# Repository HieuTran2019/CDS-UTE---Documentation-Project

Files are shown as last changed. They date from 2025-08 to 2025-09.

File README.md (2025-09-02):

# CDS-UTE Tài liệu

Cuộc thi Xe tự hành ứng dụng Xử lý ảnh và Trí tuệ nhân tạo - Tài liệu

Đây là kho lưu trữ tài liệu cho cuộc thi nội bộ về xe tự hành, áp dụng các kỹ thuật xử lý ảnh và trí tuệ nhân tạo.  
Trang Web tài liệu online: [CDS-UTE Documentation](https://cds-ute-documentation-project.readthedocs.io/en/latest/)

📌 **Mục tiêu:** Thiết kế và triển khai hệ thống xe tự hành có khả năng nhận diện làn đường, vật cản và thực hiện điều hướng tự động trong môi trường giả lập hoặc thực tế.

## Nội dung tài liệu

- Giới thiệu dự án
- Kiến trúc hệ thống
- Xử lý ảnh (Image Processing)
- Mô hình AI và điều khiển
- Môi trường mô phỏng và kiểm thử
- Tài liệu tham khảo

> Dự án lấy cảm hứng từ Bosch Future Mobility Challenge (BFMC), nhưng được tổ chức với quy mô nhỏ hơn, mang tính học thuật và thực hành.

---

📁 Đây chỉ là tài liệu nội bộ. Nếu bạn muốn đóng góp hoặc tham khảo thêm, hãy liên hệ team phát triển.

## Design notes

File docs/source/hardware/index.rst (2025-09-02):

Thông số chung và các thành phần
================================

.. toctree::
   :maxdepth: 1
   :caption: Nội dung:

   car/specs
   3d-models/in3D
   electronics/electronics

Tổng quan
-------------------

Đây là mô tả tổng quan của chiếc xe, với tất cả các thành phần của nó:

Mặt phía trên với các thành phần (minh họa ở hình 1):

- Orange Pi 5 Plus: bộ xử lý trung tâm, thực hiện các tác vụ AI, xử lý ảnh, nhận diện làn đường, biển báo và gửi tín hiệu điều khiển đến STM32.
- Board STM32F411RE: bộ điều khiển chính để điều khiển động cơ xe và servo.
- Camera Logitech: cung cấp hình ảnh cho Orange Pi.
- Công tắc nguồn: công tắc tổng, cấp nguồn từ pin LiPo 3S đến UBEC để cấp điện cho Orange Pi.
- Hai nút nhấn: nút xanh để khởi động STM32, nút đỏ để tắt chương trình chạy trên STM32.

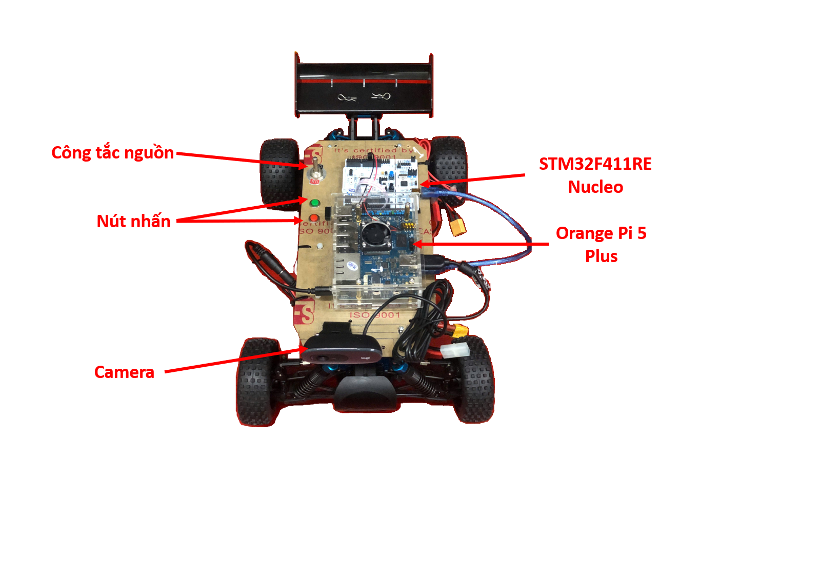
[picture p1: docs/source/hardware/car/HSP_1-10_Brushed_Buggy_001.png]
Xe HSP 1/10 Brushed Buggy


   **Hình 1.** Mặt trên của chiếc xe

------

Mặt dưới là các thành phần gồm(minh họa ở hình 2):

- Pin LiPo 3S: cung cấp điện cho Orange Pi.
- Pin Ni-MH 6 cell (7.2V) dung lượng 2000mAh: cung cấp điện cho motor và servo.
- Mạch UBEC 5V 8A: giúp ổn định nguồn 5V cho Orange Pi hoạt động.
- Mạch chia điện: do nhóm thiết kế, giúp đi dây gọn gàng, dễ thay thế, tích hợp cầu chì 3A bảo vệ servo.
- Servo: điều khiển cơ cấu lái.
- ESC: điều khiển động cơ.
- Động cơ: cung cấp mô-men xoắn, giúp xe chạy khỏe trên nhiều loại địa hình.

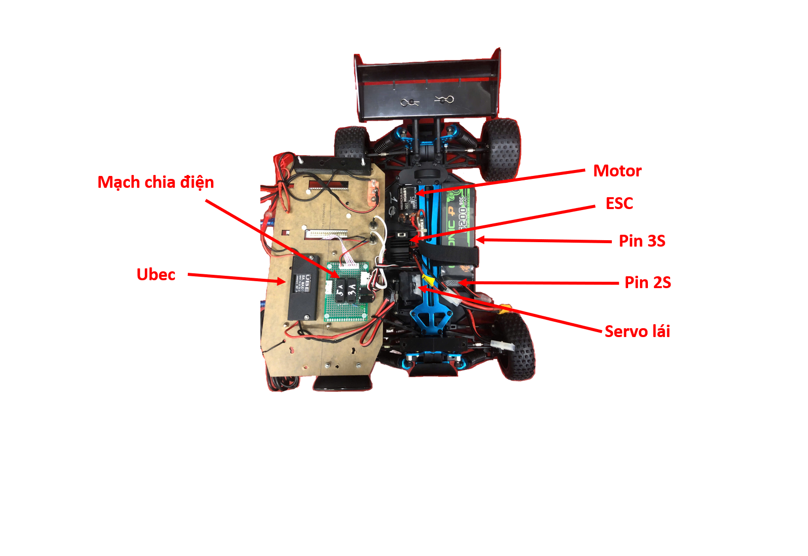
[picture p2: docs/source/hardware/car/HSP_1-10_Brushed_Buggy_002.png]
Xe HSP 1/10 Brushed Buggy


   **Hình 2.** Mặt dưới của chiếc xe

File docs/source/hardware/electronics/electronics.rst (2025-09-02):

Sơ đồ kết nối
----------------

Trong **Hình 1**, bạn có thể thấy sơ đồ kết nối của tất cả các thành phần phần cứng của xe. 
Các chân GPIO được đánh dấu trực tiếp trên từng thành phần.

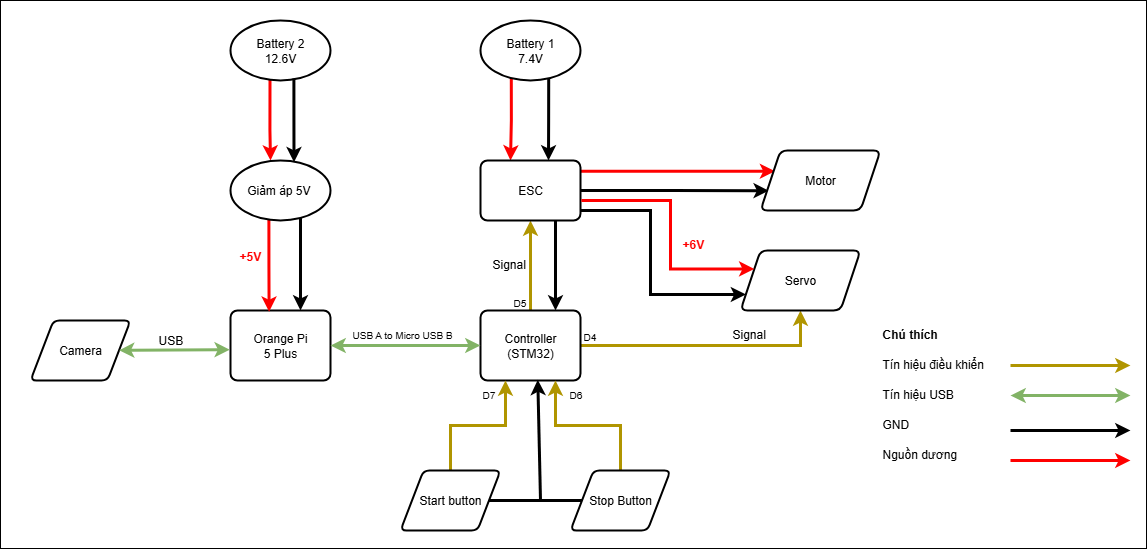
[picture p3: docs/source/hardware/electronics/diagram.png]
Sơ đồ kết nối phần cứng


   **Hình 1.** Sơ đồ kết nối tổng thể

Hệ thống sẽ sử dụng **hai cục pin**:

- **Pin LiPo 3S**: cung cấp điện cho Orange Pi, đi qua UBEC 5V (mạch giảm áp) để hạ áp xuống mức 5V.  
  UBEC giúp ổn định điện áp 5V và cung cấp dòng cao, đảm bảo Orange Pi hoạt động tốt.  

- **Pin Ni-MH 6 cell**: cung cấp điện cho ESC để điều khiển động cơ.  
  Đồng thời nguồn từ ESC cũng cấp cho servo, nhưng được đưa qua một cầu chì 3A để tránh quá tải, bảo vệ servo.  

**STM32** được cấp nguồn thông qua cổng USB mini từ Orange Pi.  
Cần chú ý jumper trên board STM32 phải chọn **USB** thay vì **E5V** (vị trí khoanh đỏ số 1 trong Hình 2).  
Ngoài ra, dù sử dụng nhiều nguồn khác nhau, tất cả cần **đồng bộ chung GND** để tín hiệu điều khiển chính xác (xem Hình 2 và Hình 3).  

STM32 được kết nối đến **mạch chia điện** thông qua dây bus (ô đỏ số 3 trong Hình 2).  
Cần chú ý hướng cắm, chân bắt đầu từ D7 đến D2.  

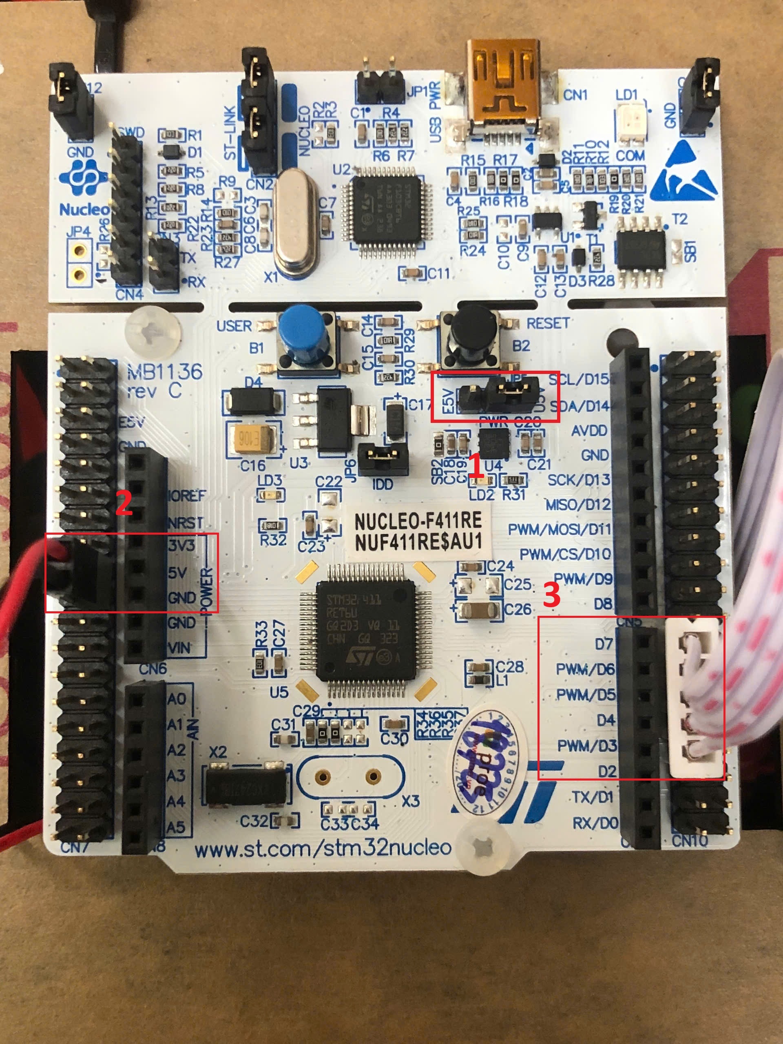
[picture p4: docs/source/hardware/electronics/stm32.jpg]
STM32 kết nối nguồn và mạch chia điện


   **Hình 2.** STM32 và các kết nối quan trọng

Đây là **mạch chia điện**, các đầu connector được thiết kế giống với sơ đồ tổng thể ở Hình 1.  
Các đầu nối loại XH2.54mm giúp việc thay thế và sửa chữa thuận tiện hơn.  
Trên board còn có **LED màu xanh lá** để báo hiệu có điện từ ESC.

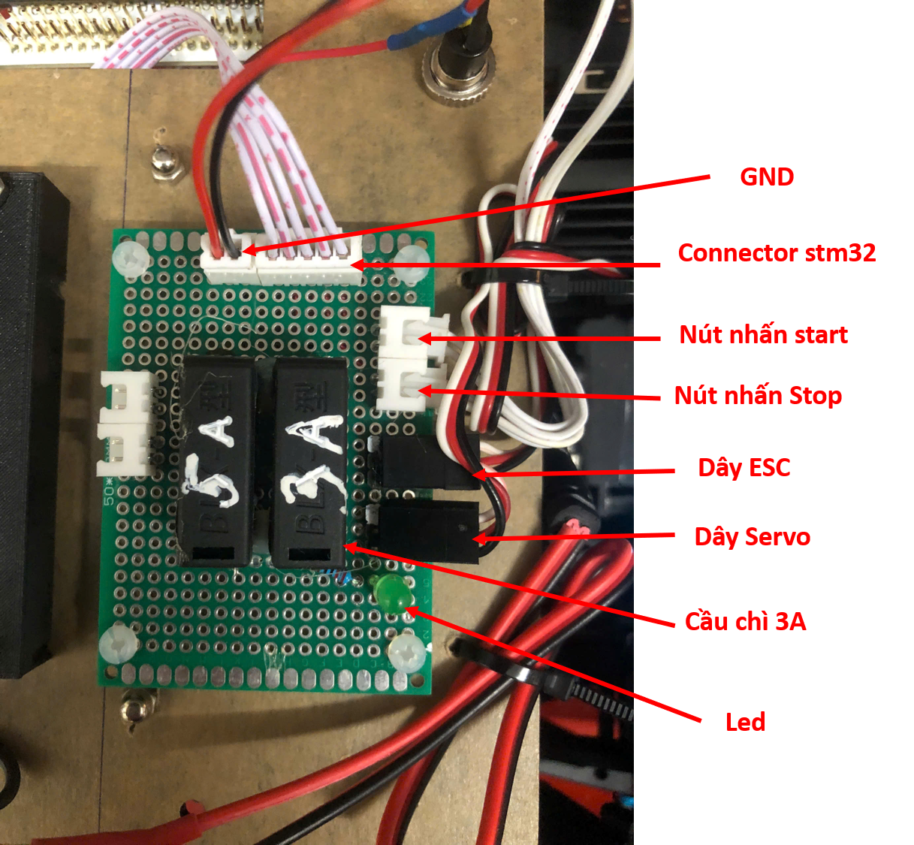
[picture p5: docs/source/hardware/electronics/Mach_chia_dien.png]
Mạch chia điện


   **Hình 3.** Mạch chia điện

Xe được trang bị **hai nút nhấn** (màu xanh và màu đỏ), đều được lập trình bằng ngắt ngoài:  

- **Nút đỏ**: dừng chương trình điều khiển. Khi nhấn, tốc độ (`speed`) và góc lái (`angle`) sẽ trở về 0, đồng thời LED P13 tắt (Hình 4).  

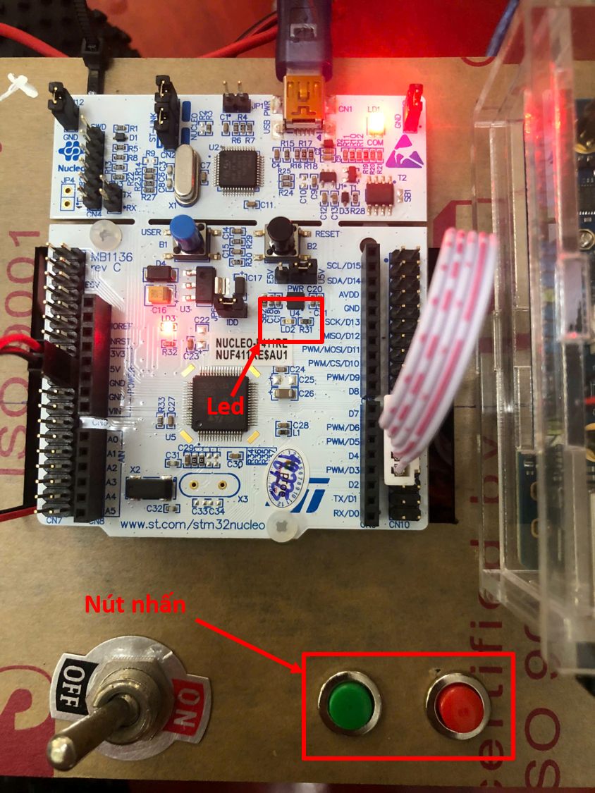
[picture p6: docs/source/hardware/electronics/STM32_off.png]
Nút đỏ dừng chương trình, LED P13 tắt


   **Hình 4.** Trạng thái khi dừng chương trình (nút đỏ – LED P13 tắt)

- **Nút xanh**: khởi động chương trình điều khiển trong STM32. Khi nhấn, LED P13 trên board STM32 sáng và chương trình bắt đầu chạy (Hình 5).  

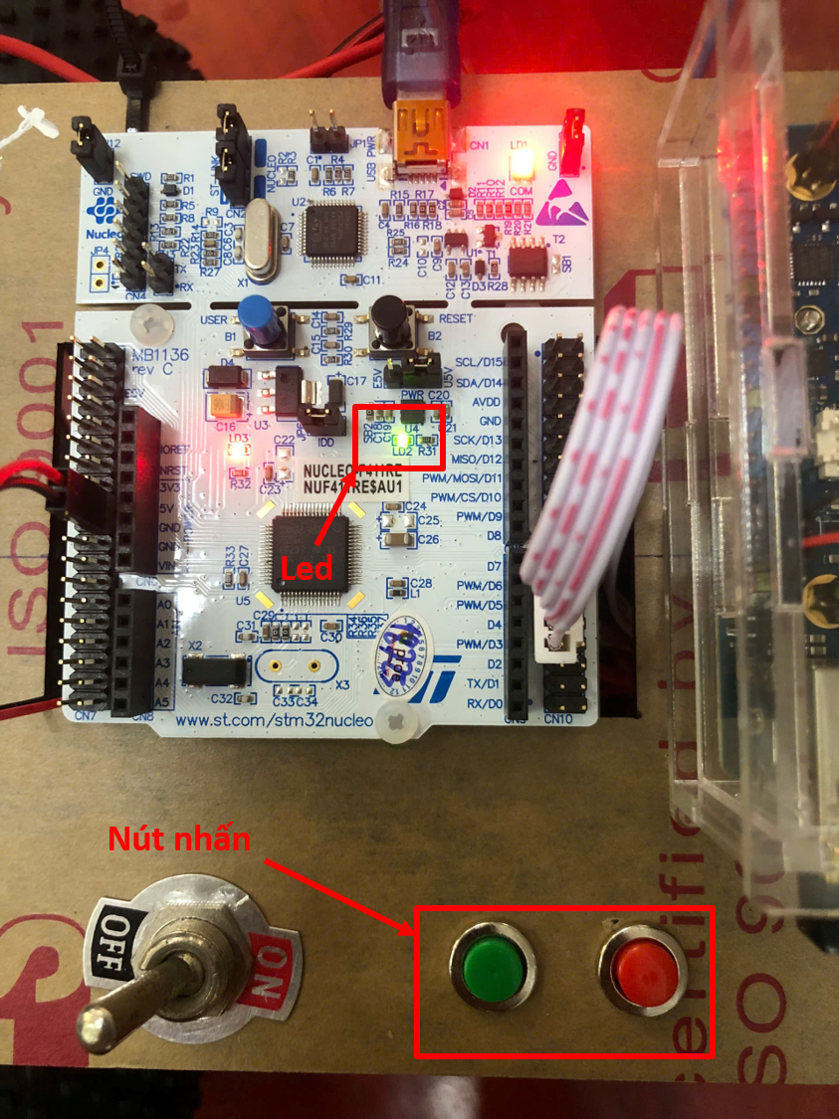
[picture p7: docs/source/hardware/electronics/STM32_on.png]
Nút xanh khởi động chương trình, LED P13 sáng


   **Hình 5.** Trạng thái khi chạy chương trình (nút xanh – LED P13 sáng)

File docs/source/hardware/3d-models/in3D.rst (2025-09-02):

Các thành phần in 3D
--------------------

Và đây là các thành phần in 3D cho chính chiếc xe. Chúng hỗ trợ liên kết các bộ phận lên khung xe. Các khối 3D trong đây là dạng tham khảo. 
Các bạn hoàn toàn có thể tự thiết kế cho mình các mẫu riêng cho bản thân
Cũng có sẵn ở định dạng có thể chỉnh sửa, như tiện ích mở rộng SLDPRT tại liên kết này: 
`solid parts <https://github.com/HieuTran2019/CDS-UTE---Documentation-Project/tree/main/docs/source/hardware/3d-models/CarSpareParts/sldprt>`_

- `Giá đỡ Camera <https://github.com/HieuTran2019/CDS-UTE---Documentation-Project/blob/main/docs/source/hardware/3d-models/CarSpareParts/C270_2020_mount.stl>`_  

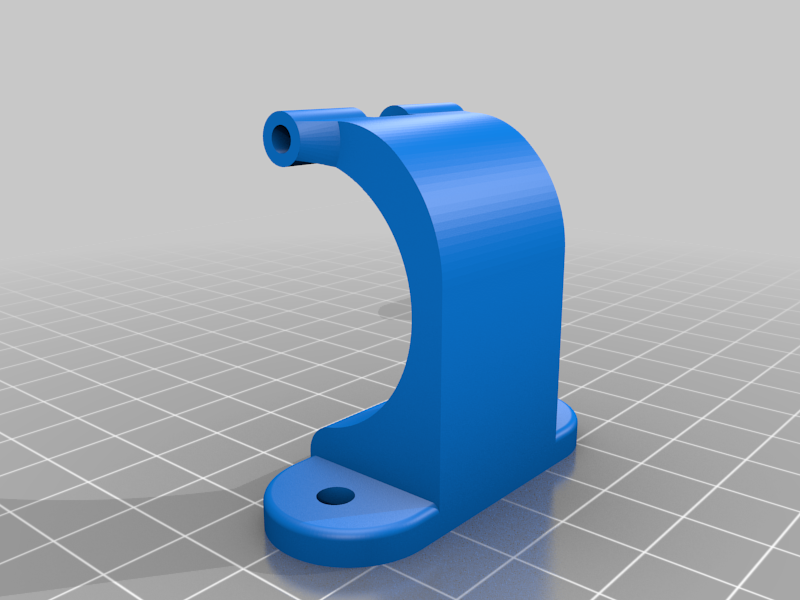
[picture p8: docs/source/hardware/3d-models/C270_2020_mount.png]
Giá đỡ Camera Logitech C270
  

- `Tấm đỡ phía sau <https://github.com/HieuTran2019/CDS-UTE---Documentation-Project/blob/main/docs/source/hardware/3d-models/CarSpareParts/besauv2.STL>`_  

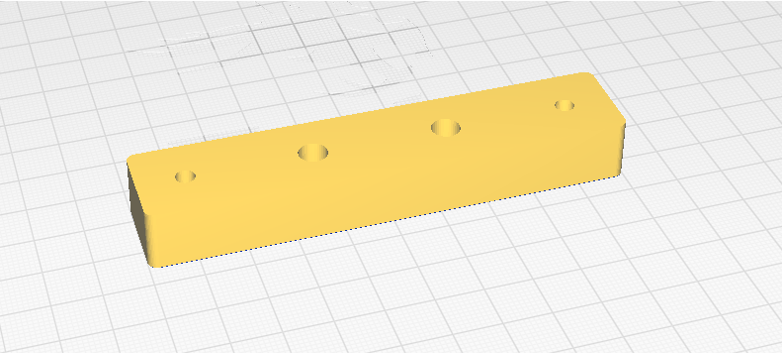
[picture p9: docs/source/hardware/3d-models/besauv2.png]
Tấm đỡ phía sau
  

- `Bệ Ubec <https://github.com/HieuTran2019/CDS-UTE---Documentation-Project/blob/main/docs/source/hardware/3d-models/CarSpareParts/be_ubec.STL>`_  

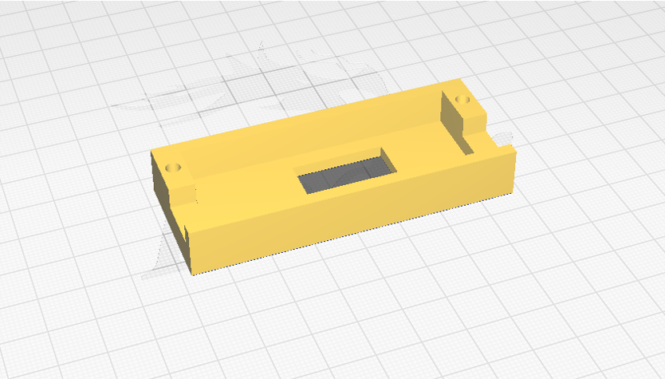
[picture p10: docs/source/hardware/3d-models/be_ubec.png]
Bệ đỡ Ubec
  

- `Bệ pin <https://github.com/HieuTran2019/CDS-UTE---Documentation-Project/blob/main/docs/source/hardware/3d-models/CarSpareParts/depin.STL>`_  

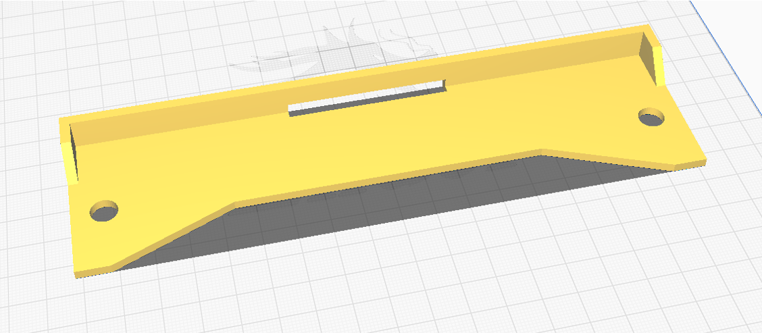
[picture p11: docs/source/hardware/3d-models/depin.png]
Bệ đỡ pin
  

- `Tấm mica <https://github.com/HieuTran2019/CDS-UTE---Documentation-Project/blob/main/docs/source/hardware/3d-models/CarSpareParts/matngang_V4.DXF>`_  

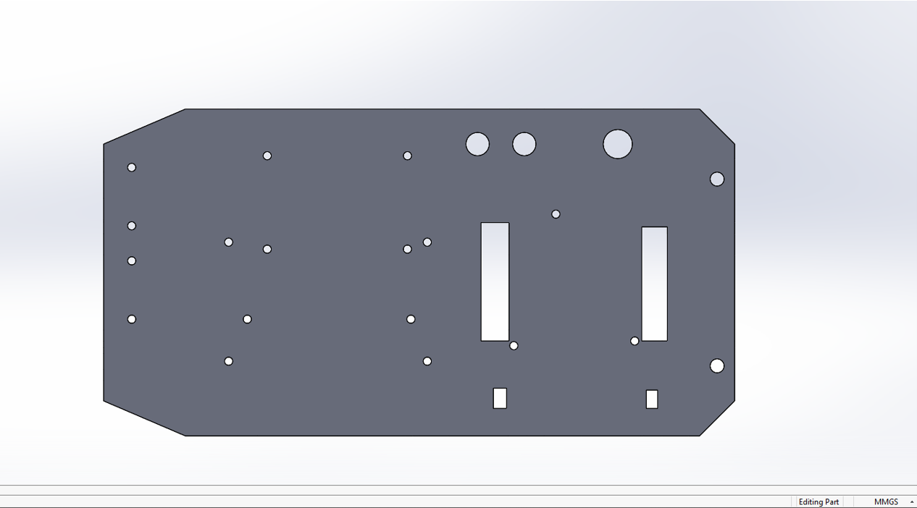
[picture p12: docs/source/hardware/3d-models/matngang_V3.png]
Tấm mica ngang
  

- `Bệ đỡ trước <https://github.com/HieuTran2019/CDS-UTE---Documentation-Project/blob/main/docs/source/hardware/3d-models/CarSpareParts/betruoc_lan2.STL>`_  

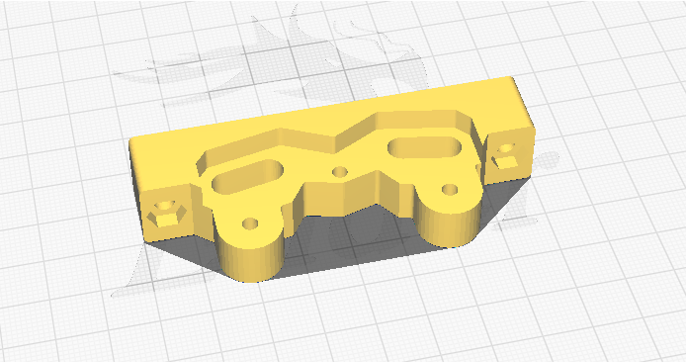
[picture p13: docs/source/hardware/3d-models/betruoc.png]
Bệ đỡ trước


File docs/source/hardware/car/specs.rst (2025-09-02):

Thành phần chi tiết
===================

Dưới đây là thông tin chi tiết các thành phần có trên xe bao gồm hình ảnh minh họa, đường link mua sản phẩm

- `Chassis <https://www.stormracer.com/sanpham/xe-dieu-khien/1-10-electric-xe-dien/hsp-1-10-electric-buggy-4wd-94107_01030089.product>`_ 

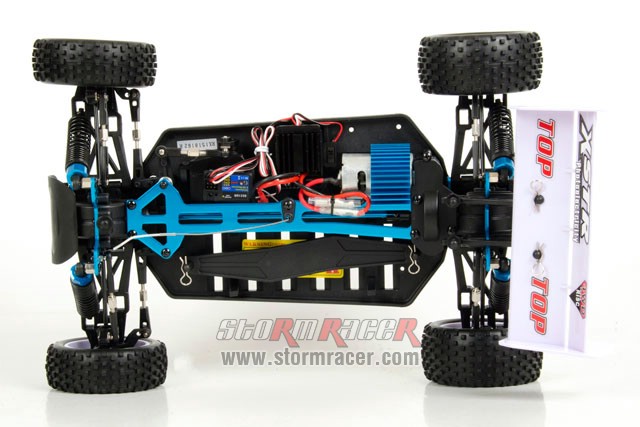
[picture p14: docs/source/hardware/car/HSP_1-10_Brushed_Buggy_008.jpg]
Chassis xe


- `Servo <https://www.stormracer.com/sanpham/xe-dieu-khien/1-10-electric-xe-dien/hsp-1-10-electric-buggy-4wd-94107_01030089.product>`_  

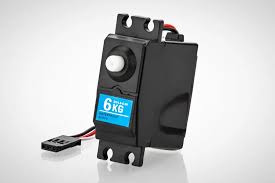
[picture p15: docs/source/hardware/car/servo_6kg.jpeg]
Servo 6kg


- `Motor 50T <https://www.stormracer.com/sanpham/dong-co-dien/motor-dien-for-rc-car/modified-motor-rs-540-50t-high-torque-brushed-motor_12050010.product>`_  
  
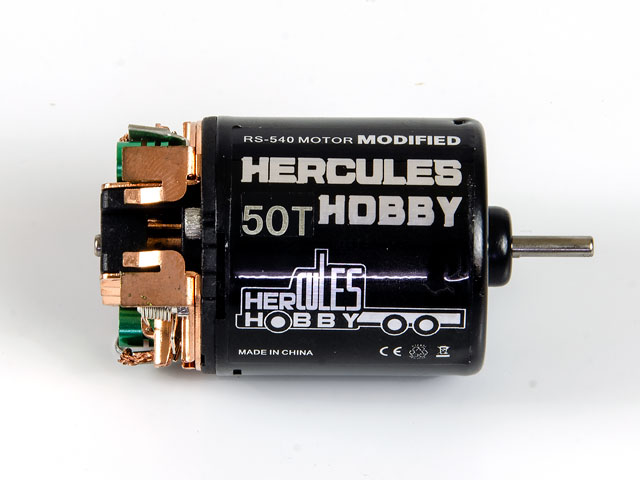
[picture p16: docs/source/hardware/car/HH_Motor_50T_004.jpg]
Động cơ RS-540 50T


- `Controller (STM32 Nucleo F411RE) <https://www.proe.vn/kit-stm32f411-nucleo-nucleo-f411re>`_  

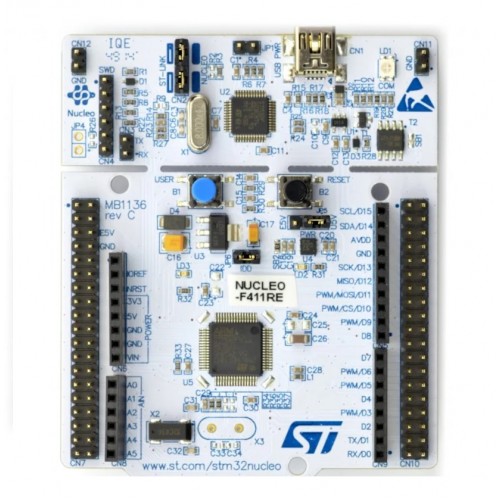
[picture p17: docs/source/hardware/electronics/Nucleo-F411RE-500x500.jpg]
STM32 Nucleo F411RE


- `Camera Logitech C270 <https://tinhocngoisao.com/products/webcam-logitech-c270-hd-720p>`_  

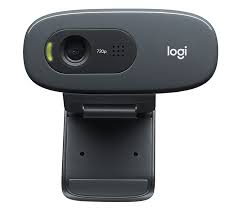
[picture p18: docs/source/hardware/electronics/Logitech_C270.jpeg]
Camera Logitech C270


- `Battery (Vant Lipo 3S 5200mAh 50C) <https://www.stormracer.com/sanpham/pin-may-sac/pin-lipo-lipo-battery/vant-battery-lipo-3s-111v-5200mah-50c-grade-a_11030088.product>`_  

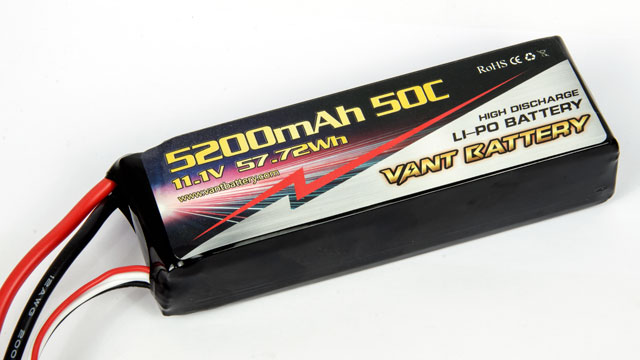
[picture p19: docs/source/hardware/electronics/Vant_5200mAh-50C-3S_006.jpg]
Pin Lipo 3S 5200mAh


.. - `IMU Sensor (BNO055) <https://www.proe.vn/adafruit-9-dof-absolute-orientation-imu-fusion-breakout-bno055>`_  

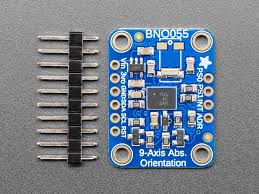
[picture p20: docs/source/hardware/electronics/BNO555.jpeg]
.. 
..     :alt: Cảm biến IMU BNO055
..     :width: 250px
..     :align: center

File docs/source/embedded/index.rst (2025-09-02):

Lập trình điều khiển
======================

Tổng quan
---------

Chương trình sẽ cung cấp cho bạn một giá trị đầu vào:

- **image**: hình ảnh trả về từ xe.  
- **Hàm điều khiển**: `control(speed, angle)` với các tham số:  

  + `angle` (góc điều khiển): giá trị trong khoảng **[-25, 25]**  
    *Âm* → góc trái, *Dương* → góc phải  

  + `speed` (tốc độ điều khiển): giá trị trong khoảng **[-25, 50]**  
    *Âm* → lùi, *Dương* → tiến  

Hướng dẫn chạy chương trình
---------------------------

Xem code tại repo:  

`CDS_UTE_2025 <https://github.com/HieuTran2019/CDS_UTE_2025>`_

Trước khi chạy, bạn cần chỉnh **port** mà STM32 kết nối với Orange Pi.  
Trên Orange Pi, thông thường port sẽ là **/dev/ttyACM0**  

port

Sau đó, để khởi chạy chương trình điều khiển, bạn dùng lệnh:

.. code-block:: bash

   python client.py

Khi chạy, tín hiệu **speed** và **angle** sẽ được gửi từ Orange Pi đến STM32 thông qua cổng **STLink** (dây cáp USB).  

**Lưu ý:** đảm bảo bạn đã nhấn nút **Start (màu xanh lá)** và LED on-board trên STM32 đã sáng.  

Hướng dẫn code STM32
---------------------

Trong dự án này, STM32 được lập trình bằng công cụ **Arduino IDE**.  
Bạn có thể xem hướng dẫn chi tiết tại:  

`utils/README.md <https://github.com/HieuTran2019/CDS_UTE_2025/blob/main/utils/README.md>`_

Phiên bản code **Control_CDS_ver3** là phiên bản hoàn thiện cuối cùng.  
Tuy nhiên, bạn hoàn toàn có thể hiệu chỉnh các tham số hoặc mở rộng thêm nếu muốn.  

Điều chỉnh tốc độ và góc lái
----------------------------

Dưới đây là hai phần hướng dẫn chi tiết để hiệu chỉnh:

.. toctree::
   :maxdepth: 2
   :caption: Nội dung:

   img/speed
   img/angle

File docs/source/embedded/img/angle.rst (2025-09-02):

Hiệu chỉnh góc lái
==================

Mỗi chiếc xe RC đều được lắp ráp tỉ mỉ, tuy nhiên có thể tồn tại sai số nhỏ trong hiệu chỉnh góc lái do cơ cấu cơ khí.  
Ví dụ: khi bạn đặt góc lái thẳng (90°), bánh xe thực tế có thể lệch vài độ sang trái hoặc phải. Đây không phải lỗi, mà là đặc điểm tự nhiên của quá trình lắp ráp thủ công.

Giải pháp
---------

Để khắc phục sai số này, tôi thiết lập các tham số khởi tạo nhằm giới hạn và hiệu chỉnh lại góc lái.

Tham khảo code Arduino tại đây:  
`Control_CDS_ver3.ino <https://github.com/HieuTran2019/CDS_UTE_2025/blob/main/utils/Control_CDS_ver3/Control_CDS_ver3.ino>`_

Ở đầu code, bạn sẽ thấy các tham số cố định (Hình 1):

Tham số cấu hình góc lái

   **Hình 1.** Các tham số cấu hình góc lái trong code

Nguyên lý tín hiệu Servo
------------------------

Servo lái được điều khiển dựa vào độ rộng xung PWM:

- **1000µs → 1500µs**: quay sang trái (0° → 90°)  
- **1500µs**: vị trí trung tâm (90°)  
- **1500µs → 2000µs**: quay sang phải (90° → 180°)  

Một số điểm quan trọng:

- Cơ cấu lái thực tế của xe **không sử dụng toàn bộ dải 0° → 180° của servo**.  
  Giới hạn an toàn thường nằm trong khoảng **50° → 130°**.  
- Vượt quá giới hạn này có thể khiến servo bị kẹt, quá tải và cháy; hoặc làm gãy các khớp cơ khí (Hình 2).  
- Nếu ở vị trí **90° không trùng với hướng thẳng của xe**, bạn có thể hiệu chỉnh lại bằng tham số `SERVO_CENTER`.

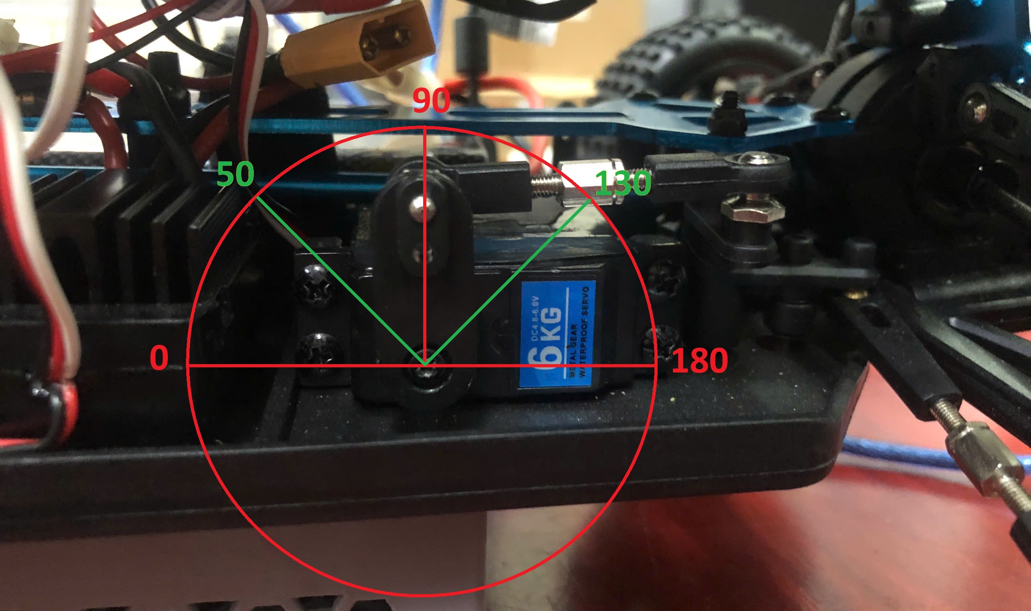
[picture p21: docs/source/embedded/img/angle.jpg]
Giới hạn góc lái


   **Hình 2.** Giới hạn góc lái an toàn

Tổng kết các tham số
--------------------

Bạn có thể tinh chỉnh lại các tham số góc lái để phù hợp với từng xe:

1. Chỉnh sửa trong file code Arduino  
   `Control_CDS_ver3.ino <https://github.com/HieuTran2019/CDS_UTE_2025/blob/main/utils/Control_CDS_ver3/Control_CDS_ver3.ino>`_:

- `SERVO_LEFT_MAX  = 50;`   → Góc trái tối đa  
- `SERVO_CENTER    = 90;`   → Vị trí trung tâm  
- `SERVO_RIGHT_MAX = 130;`  → Góc phải tối đa  

2. Chỉnh sửa trong file Python  
   `control.py <https://github.com/HieuTran2019/CDS_UTE_2025/blob/main/utils/control.py>`_:

- `speed = max(min(speed, 50), -25)`  
  → Giới hạn tốc độ do phần mềm. Xe không bao giờ vượt quá 50 (tiến) hoặc -25 (lùi).  

- `angle = max(min(angle, 25), -25)`  
  → Giới hạn góc lái trong khoảng [-25°, 25°] để tránh servo vượt quá giới hạn cơ khí.  

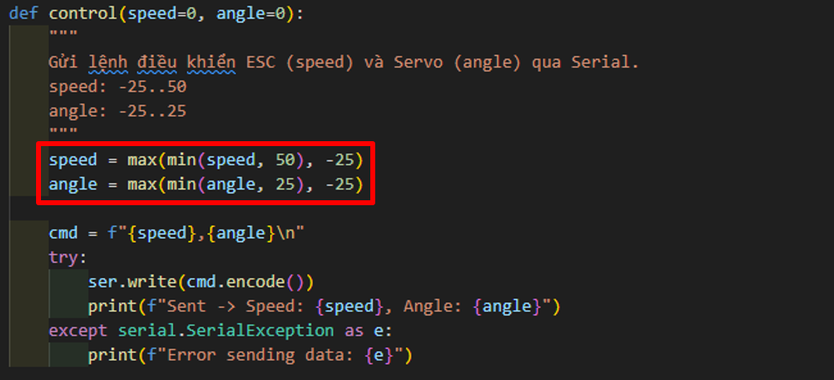
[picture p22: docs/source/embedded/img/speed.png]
Giới hạn tốc độ


   **Hình 3.** Điều chỉnh giới hạn tốc độ trong code

Ví dụ cấu hình:

.. code-block:: cpp

    // Giới hạn servo lái
    const int SERVO_LEFT_MAX  = 50;   // Góc trái tối đa
    const int SERVO_CENTER    = 90;   // Trung tâm
    const int SERVO_RIGHT_MAX = 130;  // Góc phải tối đa

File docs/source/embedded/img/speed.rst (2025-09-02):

Hiệu chỉnh tốc độ
=================

Như một phần trong cam kết mang đến trải nghiệm tốt nhất, mỗi người tham gia sẽ nhận được một chiếc xe RC đã được lắp ráp tỉ mỉ.  
Tuy nhiên, có thể tồn tại những sai số nhỏ trong hiệu chỉnh tốc độ do quá trình lắp ráp thủ công.  

Đây không phải là lỗi, mà là đặc điểm tự nhiên trong sản xuất và có thể hiệu chỉnh bằng phần mềm.

Giải pháp
---------

Để khắc phục sai số này, tôi đã thiết lập các tham số khởi tạo nhằm xử lý những sai số nhỏ này trong hiệu chỉnh góc lại.

Về điều khiển, tôi sử dụng **thư viện Servo** để điều khiển ESC (Electronic Speed Controller), vì ESC cũng nhận tín hiệu xung trong khoảng **1000µs → 2000µs**.

Tham khảo code Arduino tại đây:  
`Control_CDS_ver3.ino <https://github.com/HieuTran2019/CDS_UTE_2025/blob/main/utils/Control_CDS_ver3/Control_CDS_ver3.ino>`_

Ở đầu code, bạn sẽ thấy các tham số cố định (Hình 1):

Tham số cấu hình PWM

   **Hình 1.** Các tham số cấu hình PWM trong code

Nguyên lý tín hiệu ESC
----------------------

ESC điều khiển tiến/lùi dựa vào độ rộng xung PWM:

- **1000µs → 1500µs**: Lùi (-100% → 0%)  
- **1500µs**: Trung tính (0%, xe dừng)  
- **1500µs → 2000µs**: Tiến (0% → 100%)  

Một số điểm quan trọng:

- Nếu không cần tốc độ tối đa, hãy **giới hạn PWM_FORWARD_MAX**  
  Ví dụ: `PWM_FORWARD_MAX = 1700` → tốc độ tối đa chậm hơn so với 2000µs.

- Khi lùi:  

  1. Gửi tín hiệu nhỏ hơn 1300µs (ví dụ 1200µs) trong ~300ms để ESC xác nhận.  
  2. Trả lại **neutral = 1500µs**.  
  3. Sau đó mới gửi dải xung 1500 → 1000µs để xe lùi.  

- Khi phanh:  
  Nếu xe đang chạy tiến (`> 1500µs`), chỉ cần gửi tín hiệu `< 1200µs`, xe sẽ **phanh gấp**.  
  Cách này hiệu quả hơn so với chỉ trả về **1500µs** (xe sẽ trôi). (chưa tích hợp vào code Control_CDS_ver3)  

Hàm điều khiển ESC
------------------

Hình 2 minh họa hàm điều khiển ESC trong STM32:

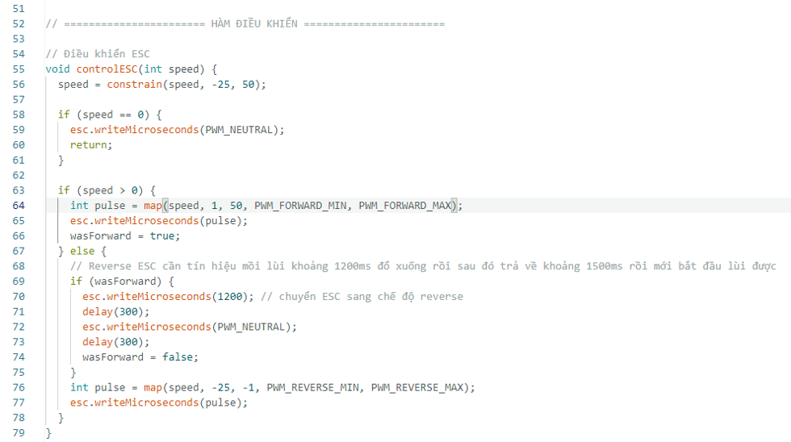
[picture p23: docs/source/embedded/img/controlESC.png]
Hàm điều khiển ESC


   **Hình 2.** Hàm điều khiển ESC trong code STM32

Tổng kết các tham số
--------------------

Bạn có thể tinh chỉnh lại các tham số PWM và giới hạn phần mềm để phù hợp với từng xe.

1. Chỉnh sửa trong file code Arduino  
   `Control_CDS_ver3.ino <https://github.com/HieuTran2019/CDS_UTE_2025/blob/main/utils/Control_CDS_ver3/Control_CDS_ver3.ino>`_:

- `PWM_NEUTRAL      = 1500`   → Vị trí trung tính (xe đứng yên)  
- `PWM_FORWARD_MIN  = 1550`   → Ngưỡng bắt đầu tiến (tăng nếu xe chưa chạy được)  
- `PWM_FORWARD_MAX  = 1700`   → Giới hạn tốc độ tiến tối đa (giảm nếu muốn xe chậm lại)  
- `PWM_REVERSE_MIN  = 1250`   → Giới hạn tốc độ lùi tối đa (tăng nếu muốn xe lùi chậm lại)  
- `PWM_REVERSE_MAX  = 1350`   → Ngưỡng bắt đầu lùi (giảm nếu xe không lùi được)  

2. Chỉnh sửa trong file Python  
   `control.py <https://github.com/HieuTran2019/CDS_UTE_2025/blob/main/utils/control.py>`_:

- `speed = max(min(speed, 50), -25)`  
  → Giới hạn tốc độ do phần mềm. Xe không bao giờ vượt quá 50 (tiến) hoặc -25 (lùi).  

- `angle = max(min(angle, 25), -25)`  
  → Giới hạn góc lái trong khoảng [-25°, 25°] để tránh servo vượt quá giới hạn cơ khí.  

Giới hạn tốc độ

   **Hình 3.** Điều chỉnh giới hạn tốc độ trong code

Ví dụ cấu hình trong Arduino:

.. code-block:: cpp

    // Giới hạn xung PWM ESC
    const int PWM_NEUTRAL     = 1500;   // Giá trị trung tính (xe đứng yên)
    const int PWM_FORWARD_MIN = 1550;   // Ngưỡng bắt đầu tiến
    const int PWM_FORWARD_MAX = 1700;   // Giới hạn tốc độ tiến tối đa
    const int PWM_REVERSE_MIN = 1250;   // Giới hạn tốc độ lùi tối đa
    const int PWM_REVERSE_MAX = 1350;   // Ngưỡng bắt đầu lùi

Tham khảo thêm:  
`Điều khiển ESC <https://github.com/Tales-sv/Esp32-ESC_Controler>`_

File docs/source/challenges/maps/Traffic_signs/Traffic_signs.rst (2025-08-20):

Biển báo giao thông
===================

Trên đường đua có thể xuất hiện các biển báo giao thông sau:

- Biển đi thẳng
- Biển rẽ trái
- Biển rẽ phải
- Biển cấm đi thẳng
- Biển cấm rẽ trái
- Biển cấm rẽ phải
- Biển STOP
- Biển đỗ xe (nâng cao)
- Biển báo nhiễu (nâng cao)

Bạn có thể tìm thấy các biển báo giao thông ở định dạng PDF (in ở khổ A4) tại đây:  `📄 Traffic signs <https://github.com/HieuTran2019/CDS-UTE---Documentation-Project/blob/main/docs/source/challenges/maps/Traffic_signs/bienbao_2.pdf>`_

Mỗi dấu hiệu được gói gọn trong một hình vuông **6x6 cm** (tỷ lệ tương ứng). Ví dụ minh họa:  

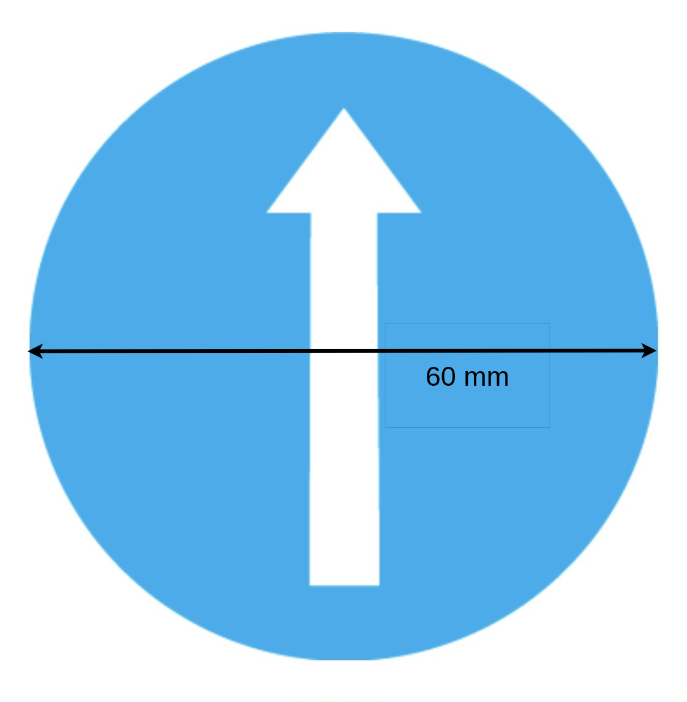
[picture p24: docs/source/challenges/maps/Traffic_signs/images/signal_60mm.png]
Ví dụ biển báo 6x6 cm


   **Hình 1.** Ví dụ biển báo kích thước 6x6 cm

Mỗi dấu hiệu được gắn trên đỉnh của một **trụ cột**, làm cho biển báo nằm ở mức **~17 cm**.  

Biển báo gắn trên trụ cột 17cm

   **Hình 2.** Ví dụ biển báo trên cột cao 17 cm

Mô hình 3D cột biển báo
-----------------------

Dưới đây là các mô hình 3D (STL) của trụ biển báo:

- `🗂 Chân trụ biển báo <https://github.com/HieuTran2019/CDS-UTE---Documentation-Project/blob/main/docs/source/challenges/3d-models/TrackParts/chantrubienbao_v2.STL>`_
- `🗂 Chân đế biển báo <https://github.com/HieuTran2019/CDS-UTE---Documentation-Project/blob/main/docs/source/challenges/3d-models/TrackParts/de_bien_bao_v5.STL>`_

Vị trí đặt biển báo
---------------------

Các vị trí của biển báo giao thông và đèn tín hiệu được đặt cách ~10 cm trước tín hiệu đường và ~5 cm ngoài giới hạn đường.

Vị trí biển báo trên đường đua

   **Hình 3.** Vị trí biển báo giao thông trong đường đua

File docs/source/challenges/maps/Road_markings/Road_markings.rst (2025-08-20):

Vạch kẻ đường
=============

Vạch kẻ đường có thể là nét đứt hoặc liền mạch, rộng khoảng 2cm, là vạch trắng, và khoảng cách giữa các nét đứt là 4,5cm, tương tự với vạch kẻ đường. Chiều rộng làn đường khoảng 35cm, đo từ bên trong vạch kẻ đường tương ứng.

Vạch kẻ đường cơ bản

Hình ảnh sau đây cho thấy khúc cua hẹp nhất, cũng là khúc cua phổ biến nhất trên đường ray.

Khúc cua hẹp nhất

Các loại giao lộ chính (có nhiều loại giao lộ khác trên đường ray, nhưng kích thước tương tự nhau):

Giao lộ

Giao lộ chữ T

Dưới đây là kích thước của đèn tín hiệu vạch qua đường (kích thước cũng áp dụng cho vạch qua đường trên 1 làn đường).

Vạch qua đường

Dưới đây là kích thước của các điểm đỗ xe.

Điểm đỗ xe

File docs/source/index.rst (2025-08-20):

.. CDS-UTE-Documentation-Project documentation master file, created by
   sphinx-quickstart on Wed Aug 20 18:04:21 2025.
   You can adapt this file completely to your liking, but it should at least
   contain the root `toctree` directive.

Xe Tự Hành sử dụng Xử Lý Ảnh và Trí Tuệ Nhân Tạo - Tài liệu
============================================================

**Cuộc thi Xe Tự Hành sử dụng Xử Lý Ảnh và Trí Tuệ Nhân Tạo (AVIP-AI)** là một cuộc thi kỹ thuật dành cho sinh viên, được tổ chức bởi **Trường Đại học Sư phạm Kỹ thuật TP.HCM (HCMUTE)** từ năm 2022. 
Trong cuộc thi này, các đội tham gia sẽ phát triển và triển khai các thuật toán lái xe tự hành trên một chiếc xe mô hình tỷ lệ **1/10**, do **UTE AI Lab** cung cấp. 
Tài liệu cuộc thi được tham khảo từ cuộc thi `Bosch Future Mobility Challenge (BFMC) <https://bosch-future-mobility-challenge-documentation.readthedocs-hosted.com/index.html>`_.

Xem chi tiết tài liệu tại Github `repo <https://github.com/HieuTran2019/CDS-UTE---Documentation-Project>`_.

Tài liệu chính thức này cung cấp hướng dẫn toàn diện, bao gồm:

- Mô tả mã nguồn được cung cấp
- Tổng quan chi tiết về đường đua và các yếu tố trên đường
- Sơ đồ hệ thống và kiến trúc phần cứng
- Hướng dẫn cài đặt và vận hành hệ thống
- Lộ trình kiến thức giúp người tham gia bắt đầu và nâng cao hiệu quả thi đấu

Tài liệu này nhằm hỗ trợ bạn trong suốt quá trình tham gia cuộc thi – từ việc thiết lập hệ thống cho đến phát triển các thuật toán điều khiển. 

**Hãy bắt đầu hành trình chinh phục xe tự hành!**

.. Add your content using ``reStructuredText`` syntax. See the
.. `reStructuredText <https://www.sphinx-doc.org/en/master/usage/restructuredtext/index.html>`_
.. documentation for details.

.. toctree::
   :maxdepth: 2
   :caption: Nội dung:

   hardware/specs
   challenges/index

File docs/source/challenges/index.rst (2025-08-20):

Thử thách cuộc thi
==================

Các xe cần vượt qua nhiều chướng ngại vật và hoàn thành đường đua trong thời gian quy định.  

.. toctree::
   :maxdepth: 2
   :caption: Nội dung

   maps/Road_markings/Road_markings
   maps/Traffic_signs/Traffic_signs
   maps/Traffic_light/Traffic_Light

Đường đua
-------------------
- `Track_Test <https://github.com/HieuTran2019/CDS-UTE---Documentation-Project/blob/main/docs/source/challenges/maps/Track_Test.png>`_
- `Race-track <https://github.com/HieuTran2019/CDS-UTE---Documentation-Project/blob/main/docs/source/challenges/maps/Track_Test.png>`_  

Kích thước thực tế của **Track_Test** là **6 x 6,4 m**.

Bản đồ thử nghiệm

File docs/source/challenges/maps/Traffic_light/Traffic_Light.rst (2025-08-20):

Đèn giao thông
==============

Đèn giao thông được thiết kế tương tự như đèn giao thông thực tế với ba màu: **đỏ, vàng và xanh lá cây**.  
Chiều cao tổng thể: **24 cm**, đường kính đèn: **4,5 cm**.  

Hệ thống đèn giao thông được tích hợp **ESP8266** và sử dụng **WebSocket** để điều khiển thủ công hoặc phát tín hiệu tự động.  
Hệ thống này do **UTE AI Lab** phát triển.  

Kích thước đèn giao thông
-------------------------

Kích thước đèn giao thông

   **Hình 1.** Kích thước mẫu của đèn giao thông

Hệ thống điều khiển đèn
-----------------------

Phần này mô tả cách hoạt động của hệ thống điều khiển thông qua WebSocket.  
*(Chưa có hình ảnh — sẽ bổ sung sau)*

Ví dụ giao diện điều khiển WebSocket

   **Hình 2.** Ví dụ giao diện điều khiển WebSocket (placeholder)

Chế độ tự động
--------------

Đèn giao thông có thể hoạt động theo chế độ tự động với chu kỳ định sẵn.  
*(Chưa có hình ảnh — sẽ bổ sung sau)*

Ví dụ chế độ tự động

   **Hình 3.** Ví dụ minh họa chế độ tự động (placeholder)

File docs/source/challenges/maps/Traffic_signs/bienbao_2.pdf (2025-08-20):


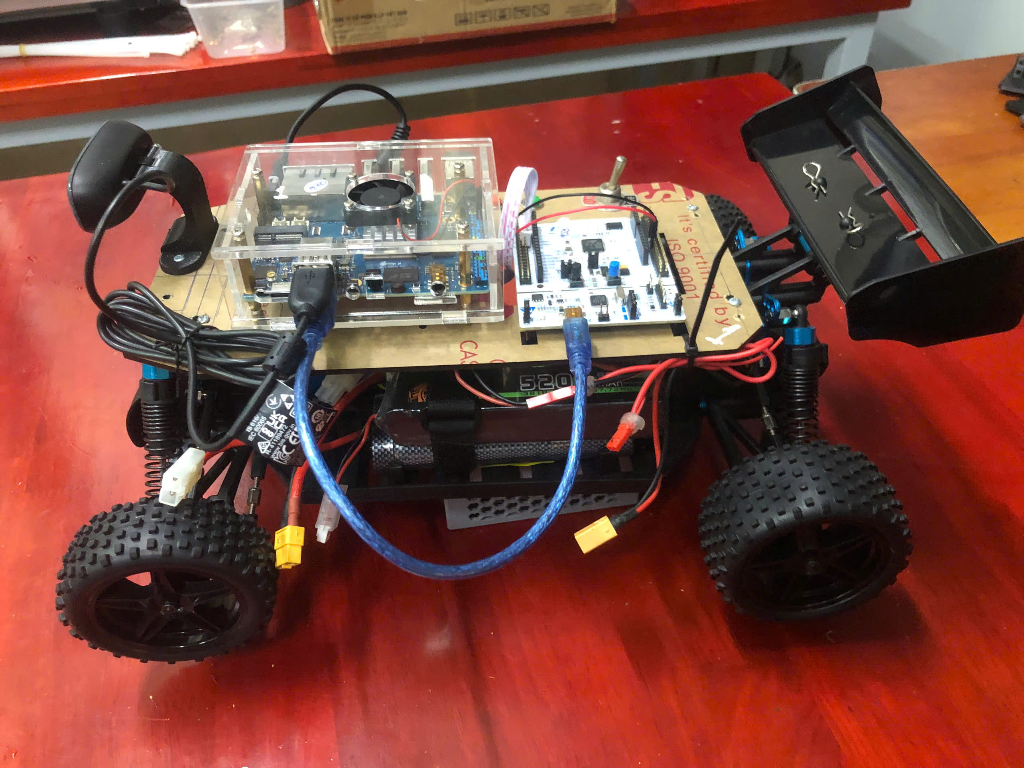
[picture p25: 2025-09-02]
docs/source/hardware/electronics/Cap_nap_STM.jpg

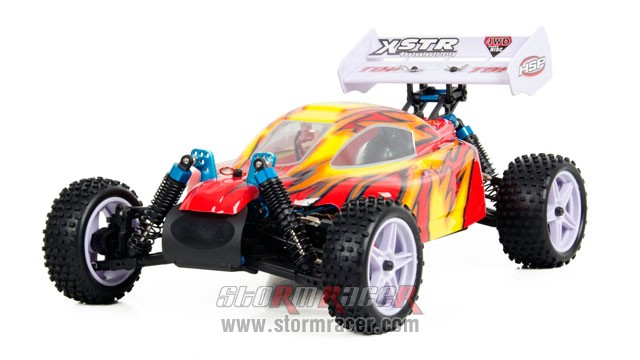
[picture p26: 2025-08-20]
docs/source/hardware/car/HSP_1-10_Brushed_Buggy_005.jpg

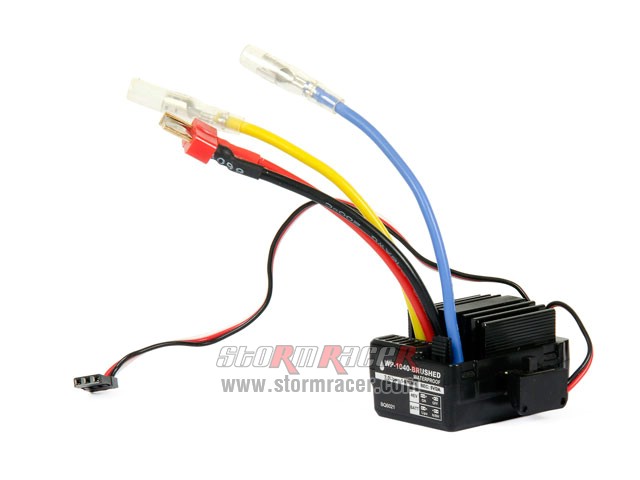
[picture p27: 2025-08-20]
docs/source/hardware/car/ESC_WP-1040-Brushed_Waterproof_002.jpg

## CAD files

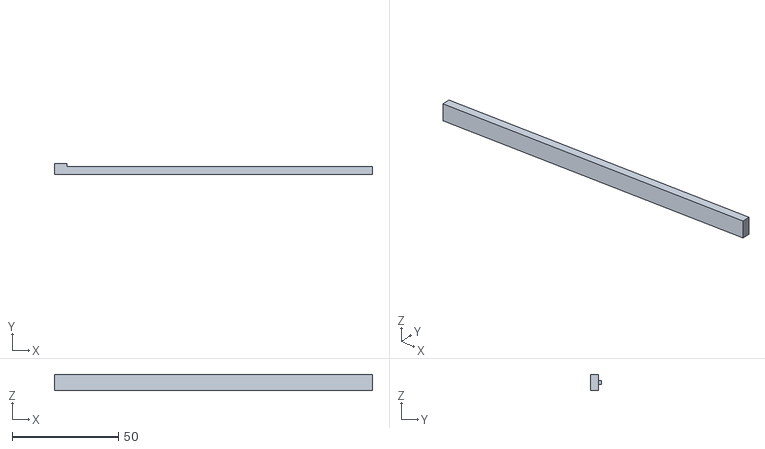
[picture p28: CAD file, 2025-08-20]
docs/source/challenges/3d-models/TrackParts/chantrubienbao_v2.STL
150.0 x 5.40 x 7.70

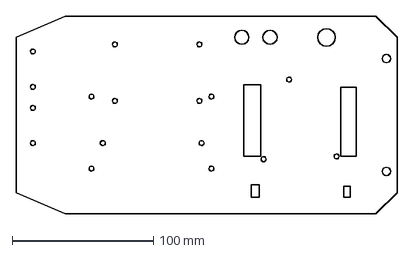
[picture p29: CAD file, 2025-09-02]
docs/source/hardware/3d-models/CarSpareParts/matngang_V4.DXF
270.0 x 140.0 mm

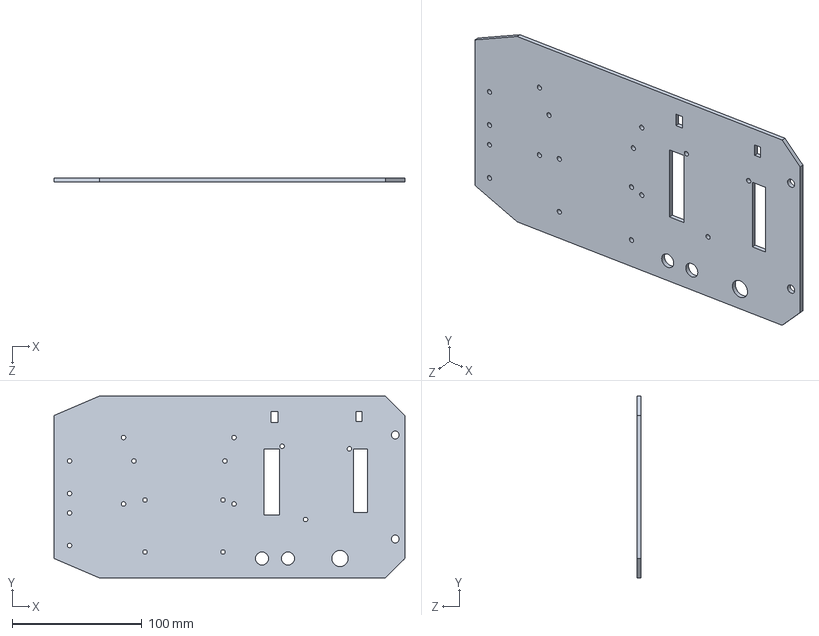
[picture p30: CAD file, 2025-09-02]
docs/source/hardware/3d-models/CarSpareParts/sldprt/matngang_V3.SLDPRT
270.0 x 140.0 x 3.00 mm

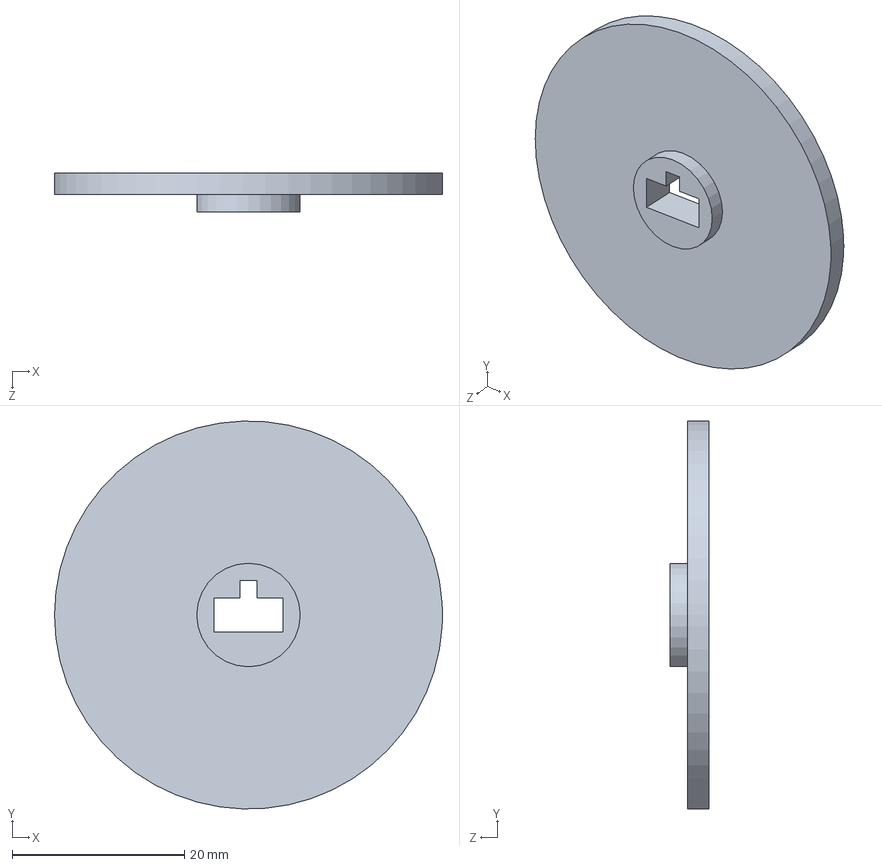
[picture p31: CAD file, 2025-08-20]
docs/source/challenges/3d-models/TrackParts/sldprt/de_bien_bao_v3.SLDPRT
45.0 x 45.0 x 4.50 mm

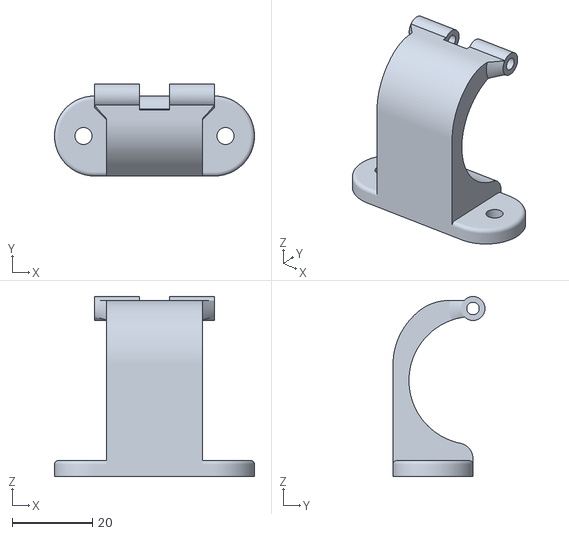
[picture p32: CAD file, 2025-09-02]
docs/source/hardware/3d-models/CarSpareParts/C270_2020_mount.stl
50.0 x 23.0 x 45.0

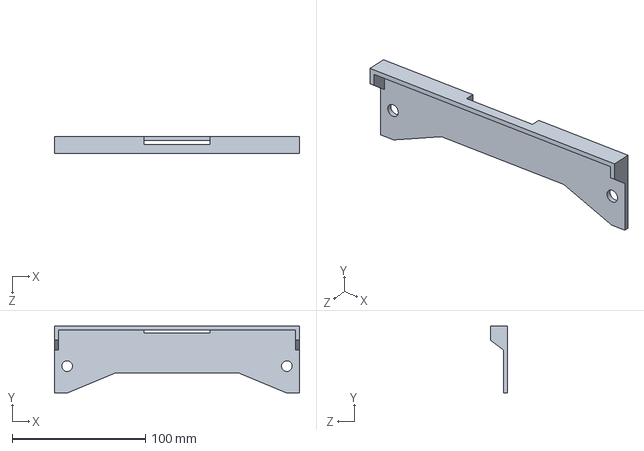
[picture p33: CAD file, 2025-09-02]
docs/source/hardware/3d-models/CarSpareParts/sldprt/depin.SLDPRT
184.0 x 50.0 x 13.0 mm

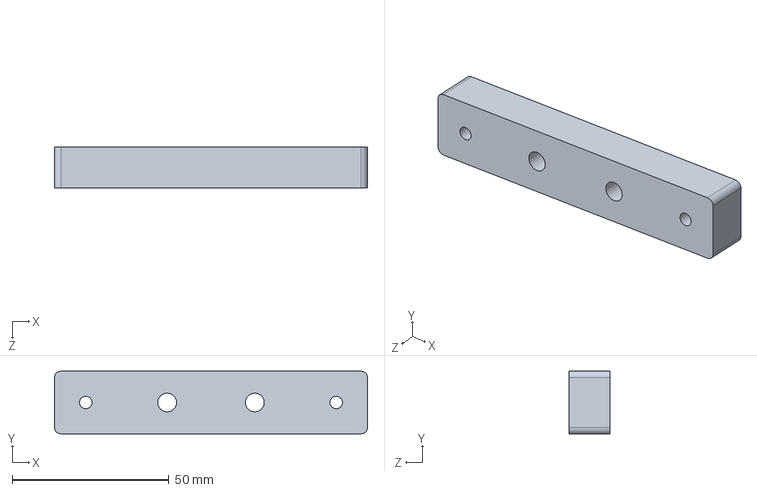
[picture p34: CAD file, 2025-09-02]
docs/source/hardware/3d-models/CarSpareParts/sldprt/besauv2.SLDPRT
100.0 x 20.0 x 13.0 mm

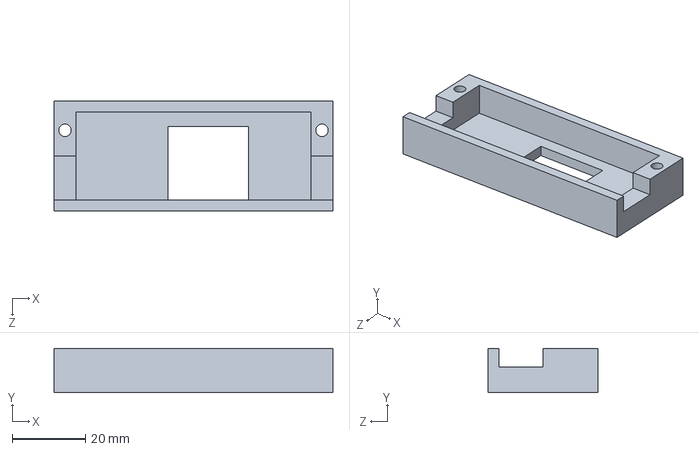
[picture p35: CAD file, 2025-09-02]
docs/source/hardware/3d-models/CarSpareParts/sldprt/be_ubec.SLDPRT
76.0 x 12.0 x 30.0 mm

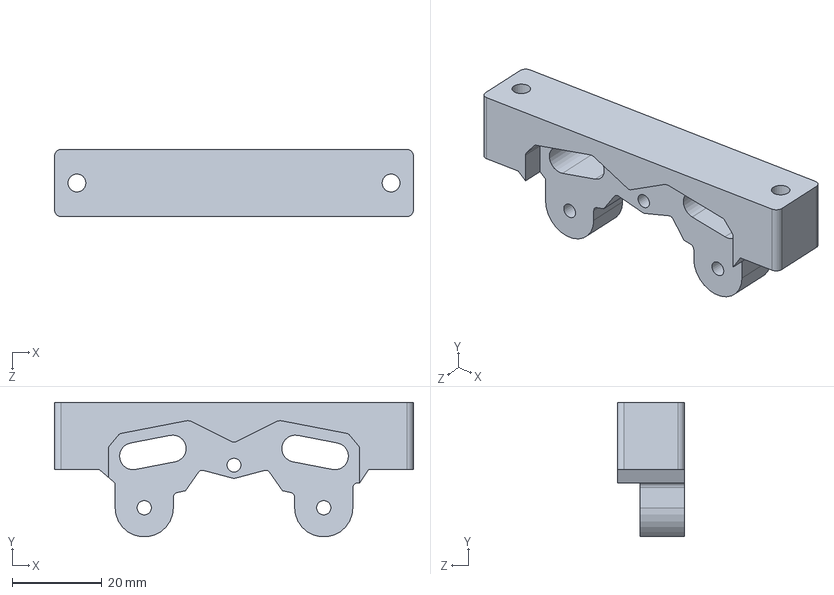
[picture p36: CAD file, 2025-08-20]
docs/source/hardware/3d-models/CarSpareParts/sldprt/betruoc_lan2.SLDPRT
80.0 x 30.0 x 15.0 mm

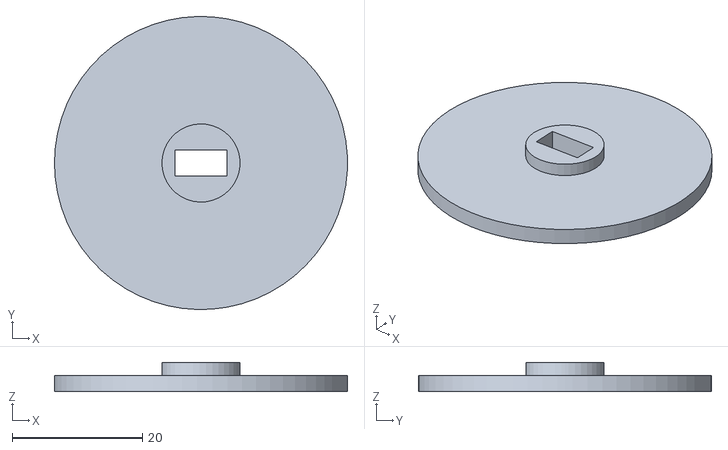
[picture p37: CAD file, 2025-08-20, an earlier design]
docs/source/challenges/3d-models/TrackParts/de_bien_bao_v4.STL
45.0 x 45.0 x 4.50

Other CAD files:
docs/source/challenges/3d-models/TrackParts/sldprt/chantrubienbao.SLDPRT
docs/source/challenges/3d-models/TrackParts/de_bien_bao_v5.STL
docs/source/challenges/3d-models/TrackParts/chantrubienbao.STL
docs/source/hardware/3d-models/CarSpareParts/be_ubec.STL
docs/source/hardware/3d-models/CarSpareParts/besauv2.STL
docs/source/hardware/3d-models/CarSpareParts/betruoc_lan2.STL
docs/source/hardware/3d-models/CarSpareParts/depin.STL

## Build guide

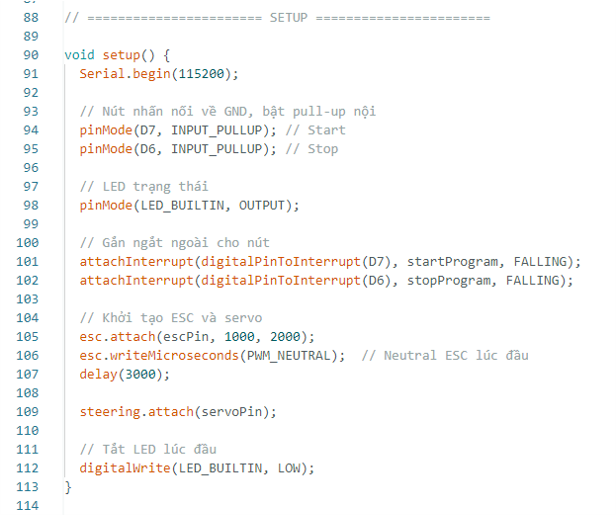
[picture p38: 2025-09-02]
docs/source/embedded/img/setup.png

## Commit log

2025-08-20 Add Sphinx documentation source
    [betruoc_lan2.SLDPRT, betruoc_lan2.STL, chantrubienbao.SLDPRT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]
2025-09-02 Upload version 2
    [C270_2020_mount.stl, be_ubec.SLDPRT, be_ubec.STL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]
